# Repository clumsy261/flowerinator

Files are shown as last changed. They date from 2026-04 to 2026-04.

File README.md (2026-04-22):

FLOWERINATOR

This "device" is more or less meant to be an easy to manage, easy to forget self managed garden, featuring growing lights, water, and anything else I cant think of a plant needs to survive. It's use can be anywhere from growing beans in a sewer to preparing a beautiful bouqet of roses for that one date that alreay is expensive enough.

While building, the esp board should be flashed with the username and the hashed pasword of the user, made on the web portal at flowerinator.free.nf. The credentials can be retrieved from the website after creating an account.

They should be inserted at this part in the code


Afterwards, you, the user can set an led growing factor (the hours/day of growing light) and the water factor (default on 1) on the settings tab.

Builders manual:

Everything is open source, documented publicly in the software and hardware directories.

The electrical components are as seen in the mentioned folders. Meanwhile, the actual design of the overall device can be left to your choosing. As long as you respect the following criteria:
-The soil should be a 20-25 cm layer
-The water tank size is almost important
-The recollection tank (residue water) should be at least half of the actual water tank
The average water consumation for three flowers would be 700-900 ml per day, so just under 3 weeks with a 20 liter design. The current template has a soil body of 100x20x25 cm.
It should look something like this:
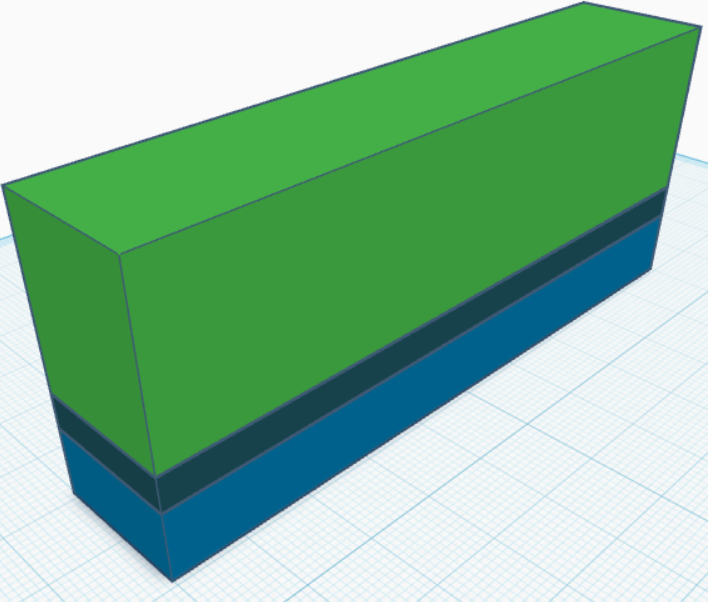
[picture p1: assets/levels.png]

-Water tank
-Residue tank
-Soil body

The ideal depth of the soil should be 25 centimeters, so we'll try staying as close to that as possible.
This project was initially meant to be programmed in rust, but that proved rather hard for me and any other who might replicate my project. Therefore everything is built in the arduino structure.

The actuall assembly proceeds like this:
-1. The wooden frame - after choosing your design dimensions, you can build a wooden box, with supports for each of the previously mentioned layers.
-2. The fluid tanks: should probably be sealed with plastic to prevent leaking, but I don't think they need to be airtight, I heard stale water is good for plants
-3. The pcb mount and the peripherals - This is the most delicate part, but I'm sure a handsome engineer such as yourself can pull it off
-4. The growing lights, the water pump and the motor are also to be mounted in the device, where the user sees fit.
(lights should be maximum 15 cm away from plant)
(water pump is advised to go into a tiny pressure tank, with three or more output valves on the ceiling for even distribution)
-5. Actually testing the systems, either by original code or by waiting a day to see the results. 

The pcb can be ordered as is on the web portal via contacting me by email or just on pcbway if you don't mind soldering the components on it. The idea is somewhat simple, you just screw the cables from the sensors and the output devices into their terminals on the board.

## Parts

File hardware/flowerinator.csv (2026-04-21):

Reference | Qty | Value | DNP | Exclude from BOM | Exclude from Board | Footprint | Datasheet
J1 | 1 | HY-SRF05 ultrasonic |  |  |  |  | https://www.aliexpress.com/item/1005007024869146.html
J2,J3,J4 | 3 | Screw_Terminal_01x02 |  |  |  | Connector_Phoenix_GMSTB:PhoenixContact_GMSTBVA_2,5_2-G_1x02_P7.50mm_Vertical | https://www.aliexpress.com/item/1005004679967893.html
J5,J6,J7,J8,J10 | 5 | Screw_Terminal_01x03 |  |  |  | Connector_Phoenix_GMSTB:PhoenixContact_GMSTBVA_2,5_3-G_1x03_P7.50mm_Vertical | https://www.aliexpress.com/item/1005004679967893.html
J9 | 1 | Screw_Terminal_01x05 |  |  |  | Connector_Phoenix_GMSTB:PhoenixContact_GMSTBVA_2,5_5-G_1x05_P7.50mm_Vertical | https://www.aliexpress.com/item/1005004679967893.html
L1 | 1 | Led Strip |  |  |  | - | https://www.aliexpress.com/item/1005007486917090.html
M1 | 1 | Motor_DC |  |  |  | 12GA-N20 Miniature DC Metal Gear Motor 3V 3.7V 5V 6V 12V Low RPM High Torque 4WD Car Electric Screwdriver Door Lock Motor | https://www.aliexpress.com/item/4001195504462.html
Q2,Q3,Q4 | 3 | FDMS8350LET40 |  |  |  | Mosfet | https://www.onsemi.com/pub/Collateral/FDMS8350LET40-D.pdf
U2 | 1 | Water sensor |  |  |  | - | https://www.aliexpress.com/item/1005007439447804.html
U3 | 1 | Touch Sensor |  |  |  | - | https://www.aliexpress.com/item/1005009348155914.html
U4 | 1 | Soil Sensor |  |  |  | Capacitive Soil Moisture Sensor Module Corrosion Resistant 3.3~5.5V for Arduino Moisture Detection | https://www.aliexpress.com/item/1005008744986367.html
U5 | 1 | Soil Sensor2 |  |  |  | Capacitive Soil Moisture Sensor Module Corrosion Resistant 3.3~5.5V for Arduino Moisture Detection | https://www.aliexpress.com/item/1005008744986367.html
U6 | 1 | ESP32-C3-DevKitM-1 |  |  |  | RF_Module:ESP32-C3-DevKitM-1 | https://docs.espressif.com/projects/esp-idf/en/latest/esp32c3/hw-reference/esp32c3/user-guide-devkitm-1.html
W1 | 1 | Water Pump |  |  |  | DC 3V 5V Micro Submersible Mini Water Pump for Aquariums Fish Tank Fountain Hydroponics | https://www.aliexpress.com/item/1005004451967987.html

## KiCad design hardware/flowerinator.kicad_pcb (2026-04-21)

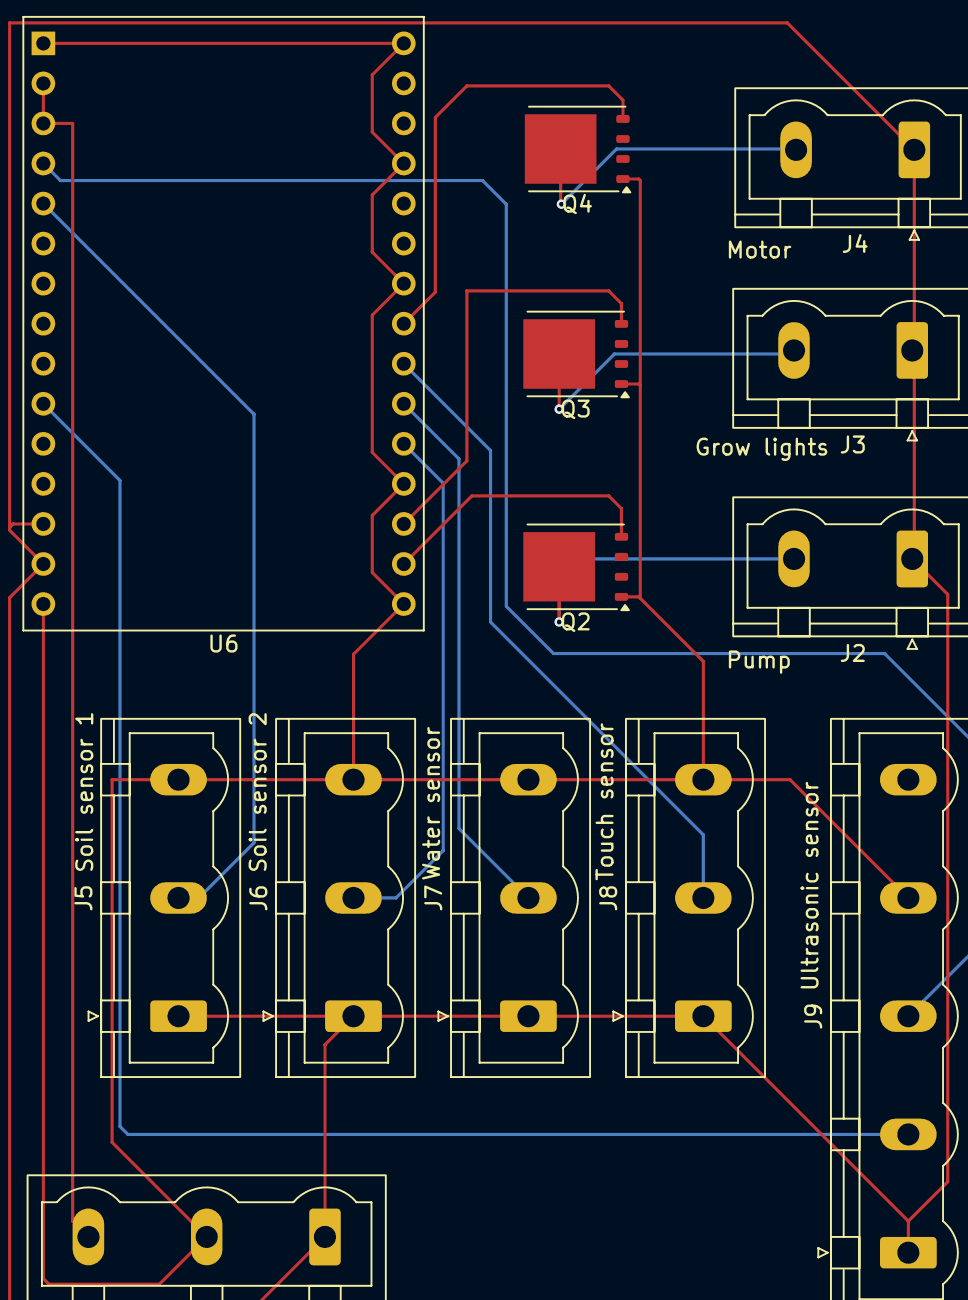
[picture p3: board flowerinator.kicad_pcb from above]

Board: 2 copper layers, 13 parts (0 on the bottom side), 15 nets.

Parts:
J2, J3, J4: Screw_Terminal_01x02; PhoenixContact_GMSTBVA_2,5_2-G_1x02_P7.50mm_Vertical
J5, J6, J7, J8, J10: Screw_Terminal_01x03; PhoenixContact_GMSTBVA_2,5_3-G_1x03_P7.50mm_Vertical
J9: Screw_Terminal_01x05; PhoenixContact_GMSTBVA_2,5_5-G_1x05_P7.50mm_Vertical
Q2, Q3, Q4: FDMS8350LET40; TDSON-8-1
U6: ESP32-C3-DevKitM-1

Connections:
unnamed: J2.2, Q2.5 (D)
unnamed: J3.2, Q3.5 (D)
unnamed: J4.2, Q4.5 (D)
unnamed: J5.2, U6.5 (IO3)
unnamed: J6.2, U6.20 (IO4)
unnamed: J7.2, U6.21 (IO5)
unnamed: J8.2, U6.22 (IO6)
unnamed: J9.2, U6.10 (IO1)
unnamed: J9.3, U6.4 (IO2)
unnamed: J2.1, J3.1, J4.1, J5.1, J6.1, J7.1, J8.1, J9.1, J10.1, U6.13 (5V), U6.14 (5V)
unnamed: J5.3, J6.3, J7.3, J8.3, J9.4, J10.2, Q2.1 (S), Q2.2 (S), Q2.3 (S), Q3.1 (S), Q3.2 (S), Q3.3 (S), Q4.1 (S), Q4.2 (S), Q4.3 (S), U6.1 (GND), U6.6 (GND), U6.8 (GND), U6.12 (GND), U6.15 (GND), U6.16 (GND), U6.19 (GND), U6.24 (GND), U6.27 (GND), U6.30 (GND)
unnamed: J10.3, U6.2 (3V3), U6.3 (3V3)
unnamed: Q2.4 (G), U6.17 (IO19)
unnamed: Q3.4 (G), U6.18 (IO18)
unnamed: Q4.4 (G), U6.23 (IO7)

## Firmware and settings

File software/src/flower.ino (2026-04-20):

///sooo how does an arduino code look like
// ESP32 WiFi Scanning example 

const String api="hashed password";//hashed password
const String user="user";//username
#define HIGH_HUMID 2000

#include "WiFi.h"
#include <string>
#include <HTTPClient.h>

#define us_trig 1  //io1
#define us_echo 2 //io2
#define soil_1 3 //io3
#define soil_2 4 //io4
#define water 5 //io5
#define touch 6 //io6
#define motor 7 //io7
#define led 18 //io18
#define pump 19 //io19

void setup() {
  Serial.begin(115200);
  Serial.println("Initializing WiFi...");
  WiFi.mode(WIFI_STA);
  Serial.println("Setup done!");
  configTime(0,0, "pool.ntp.org");
  pinMode(soil_1,INPUT);//first humidity sensor -- analogRead
  pinMode(soil_2,INPUT);//second humidity sensor -- analogRead
  pinMode(water,INPUT);//water tank sensor -- digitalRead
  pinMode(touch,INPUT);//touch sensor -- digitalRead
  pinMode(motor,OUTPUT);//height motor output
  pinMode(led,OUTPUT);//growing light output
  pinMode(pump,OUTPUT);//water pump output
  pinMode(us_trig,OUTPUT);//ultrasonic trigger
  pinMode(us_echo,INPUT);//ultrasonic echo
}

int water_ratio=50;
int led_ratio=12;

int read_height()
{
  digitalWrite(us_trig, LOW);
  delayMicroseconds(2);
  digitalWrite(us_trig, HIGH);
  delayMicroseconds(10);
  digitalWrite(us_trig, LOW);
  long duration = pulseIn(us_echo, HIGH);
  float distance = (duration * 0.0343)/2;///float value in cm
  return (int)distance;///return value in cm
}
int read_humidity() //return value from 0 to 4095
  {
    int a=analogRead(soil_1),b=analogRead(soil_2);
    return (a+b)/2;
  }
bool read_tank()
  {
    return digitalRead(water);
  }
bool plant_touch()
  {
    return digitalRead(touch);
  }
struct settings{ //height + tank -- water + led
	int first;
	int second;
}s;

settings fetch_http(settings s) //send height and tank info in a settings struct and return water and led ratio in the same struct
	{String height=String(s.first, DEC);//height
	String tank=String(s.second, DEC);//tank info
	HTTPClient http;
	String host="flowerinator.free.nf";
	String url="http://"+host+"/?api="+api+"&user="+user+"&wat="+tank+"&height="+height;
	http.begin(url);
	settings s;
	host = http.getString(); //reusing a string to save memory
	int sep = host.indexOf('\n');
	s.first= host.substring(0,sep).toInt();//water ratio
	s.second=host.substring(sep+1).toInt();//led ratio
	return s;
}
void lift_plant()
{
	if(digitalRead(touch)) return;
  bool more = 1;
  digitalWrite(motor, HIGH);
  while(more)
  {
    delay(500);
    more = digitalRead(touch);///while touching is active return 1
  }
  digitalWrite(motor,LOW);
}

void get_plant_data()
{
	s.second = read_tank();
	s.first = read_height();
}
bool inrange(int a,int water_ratio)///range for the humidity (from 0 to 4095)
{
  int p=HIGH_HUMID*water_ratio/100;
  if(a<=p) return 1;
  return 0;
}
void water_plant()
{
  digitalWrite(pump,HIGH);
  delay(3000);
  digitalWrite(pump,LOW);
}
int get_hour()
{
  time_t now;
  struct tm timeinfo;
  time(&now);
  localtime_r(&now,&timeinfo);
  return timeinfo.tm_hour;
}
void loop() {
  //the loop should do this:
	//DONE get the humidity and water the plant if necesary - also use water_ratio
  int humid=read_humidity();
  if(inrange(humid,water_ratio)) water_plant();
	//DONE find the tank status and height of the plant
	get_plant_data(); //stored in universal struct s
	///TODO connect to wifi
	Serial.println("Scanning..."); 
  int n = WiFi.scanNetworks();
  Serial.println("Scan done!");
  if (n == 0) {
    Serial.println("No networks found.");
  } else {
    Serial.println();
    Serial.print(n);
    Serial.println(" networks found");
    for (int i = 0; i < n; ++i) {
      // Print SSID and RSSI for each network found
      Serial.print(i + 1);
      Serial.print(": ");
      Serial.print(WiFi.SSID(i));
      Serial.print(" (");
      Serial.print(WiFi.RSSI(i));
      Serial.print(")");
      Serial.println((WiFi.encryptionType(i) == WIFI_AUTH_OPEN) ? " " : "*");
      delay(10);
    }
  }
  Serial.println("");
  ///DONE calculate the growing light time the plants get and turn them on/off
  int hour = get_hour()+1;
  if(hour<led_ratio) digitalWrite(led,HIGH);
  else
  digitalWrite(led,LOW);
	///DONE send data to web portal and retrieve settings
	s = fetch_http(s);
	///DONE apply 
	water_ratio=s.first;
	led_ratio = s.second%24;


  // Wait a bit before scanning again
  delay(5000);
}

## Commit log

2026-04-10 added some organised folders
    [flowerinator.kicad_pcb, flowerinator.kicad_sch]
2026-04-10 some tidying up
    [flowerinator.kicad_sch]
2026-04-10 first schematic commit
    [flowerinator.kicad_pcb, flowerinator.kicad_sch]
2026-04-13 added second humidity sensor
    [flowerinator.kicad_sch]
2026-04-14 deleted rust, going on arduino for easier to understand code
2026-04-15 resolved the dependencies for arduino
    [flower.ino]
2026-04-15 Made some adaptations for the arduino code
2026-04-16 almost finished the arduino code
    [flowerinator.kicad_sch]
2026-04-20 finished the pcb
    [flowerinator.kicad_pcb, flowerinator.kicad_sch]
2026-04-21 exported the pcb
    [flowerinator-B_Cu.gbr, flowerinator-B_Mask.gbr, flowerinator-B_Paste.gbr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]
